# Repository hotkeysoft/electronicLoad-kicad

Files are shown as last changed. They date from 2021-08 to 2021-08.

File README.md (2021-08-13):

# Electronic Load
Rev A July 2021

***Work in progress, do not use***

- USB Powered (USB-B Connector)
- 0-24V DC Input
- Adjustable current range: 0-4A
- I2C OLED 0.96" Display
- Rotary Encoder w/switch
- Temperature Sensors w/hardware shutdown
- 5V Cooling fan (PWM Speed Control)

Images
============
|Front | Back |
|---|---|
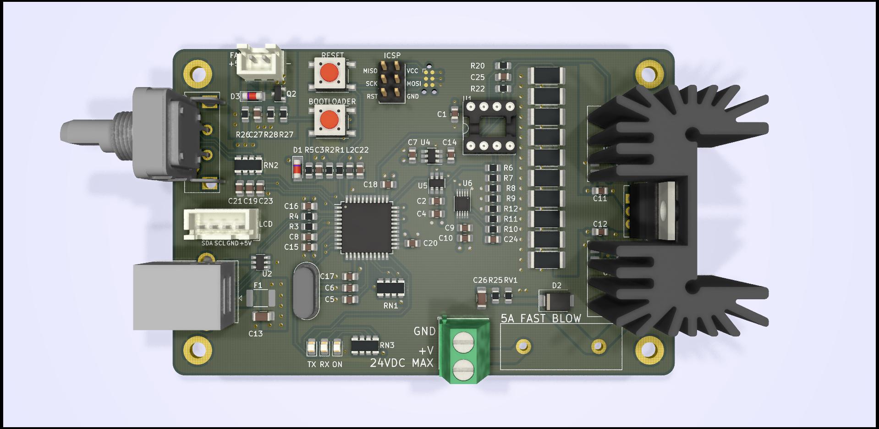
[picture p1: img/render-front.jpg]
Render Front
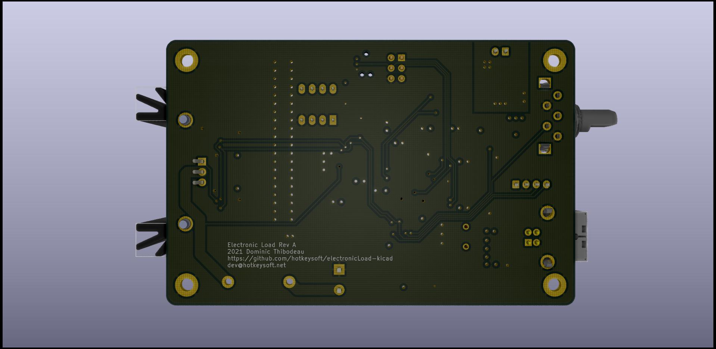
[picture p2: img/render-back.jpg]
Render Back
|||

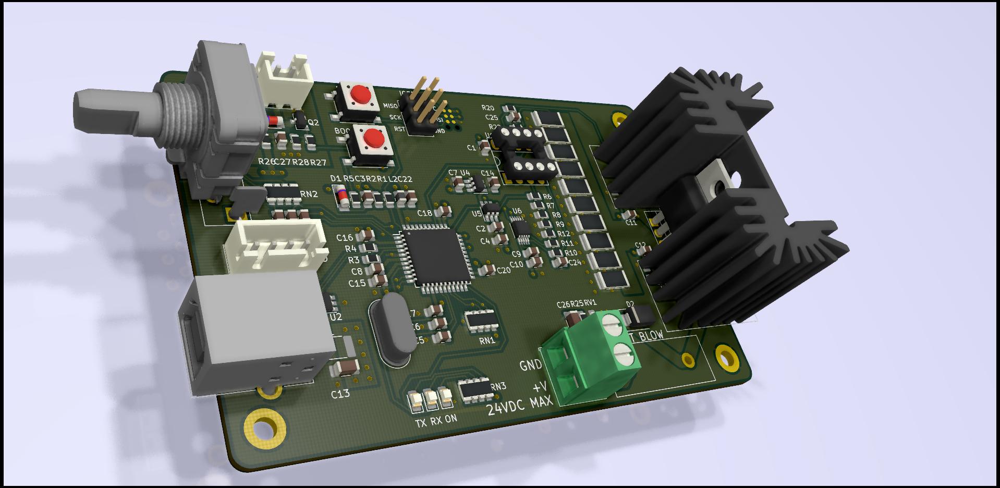
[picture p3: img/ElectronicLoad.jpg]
Render


### Schematics (pdf)
- [Complete schematics](./img/schema.pdf)

### PCB Images (svg)
- [Top](./img/pcb-front.svg)
- [GND Plane](./img/pcb-in1.svg)
- [VCC Plane](./img/pcb-in2.svg)
- [Bottom](./img/pcb-back.svg)

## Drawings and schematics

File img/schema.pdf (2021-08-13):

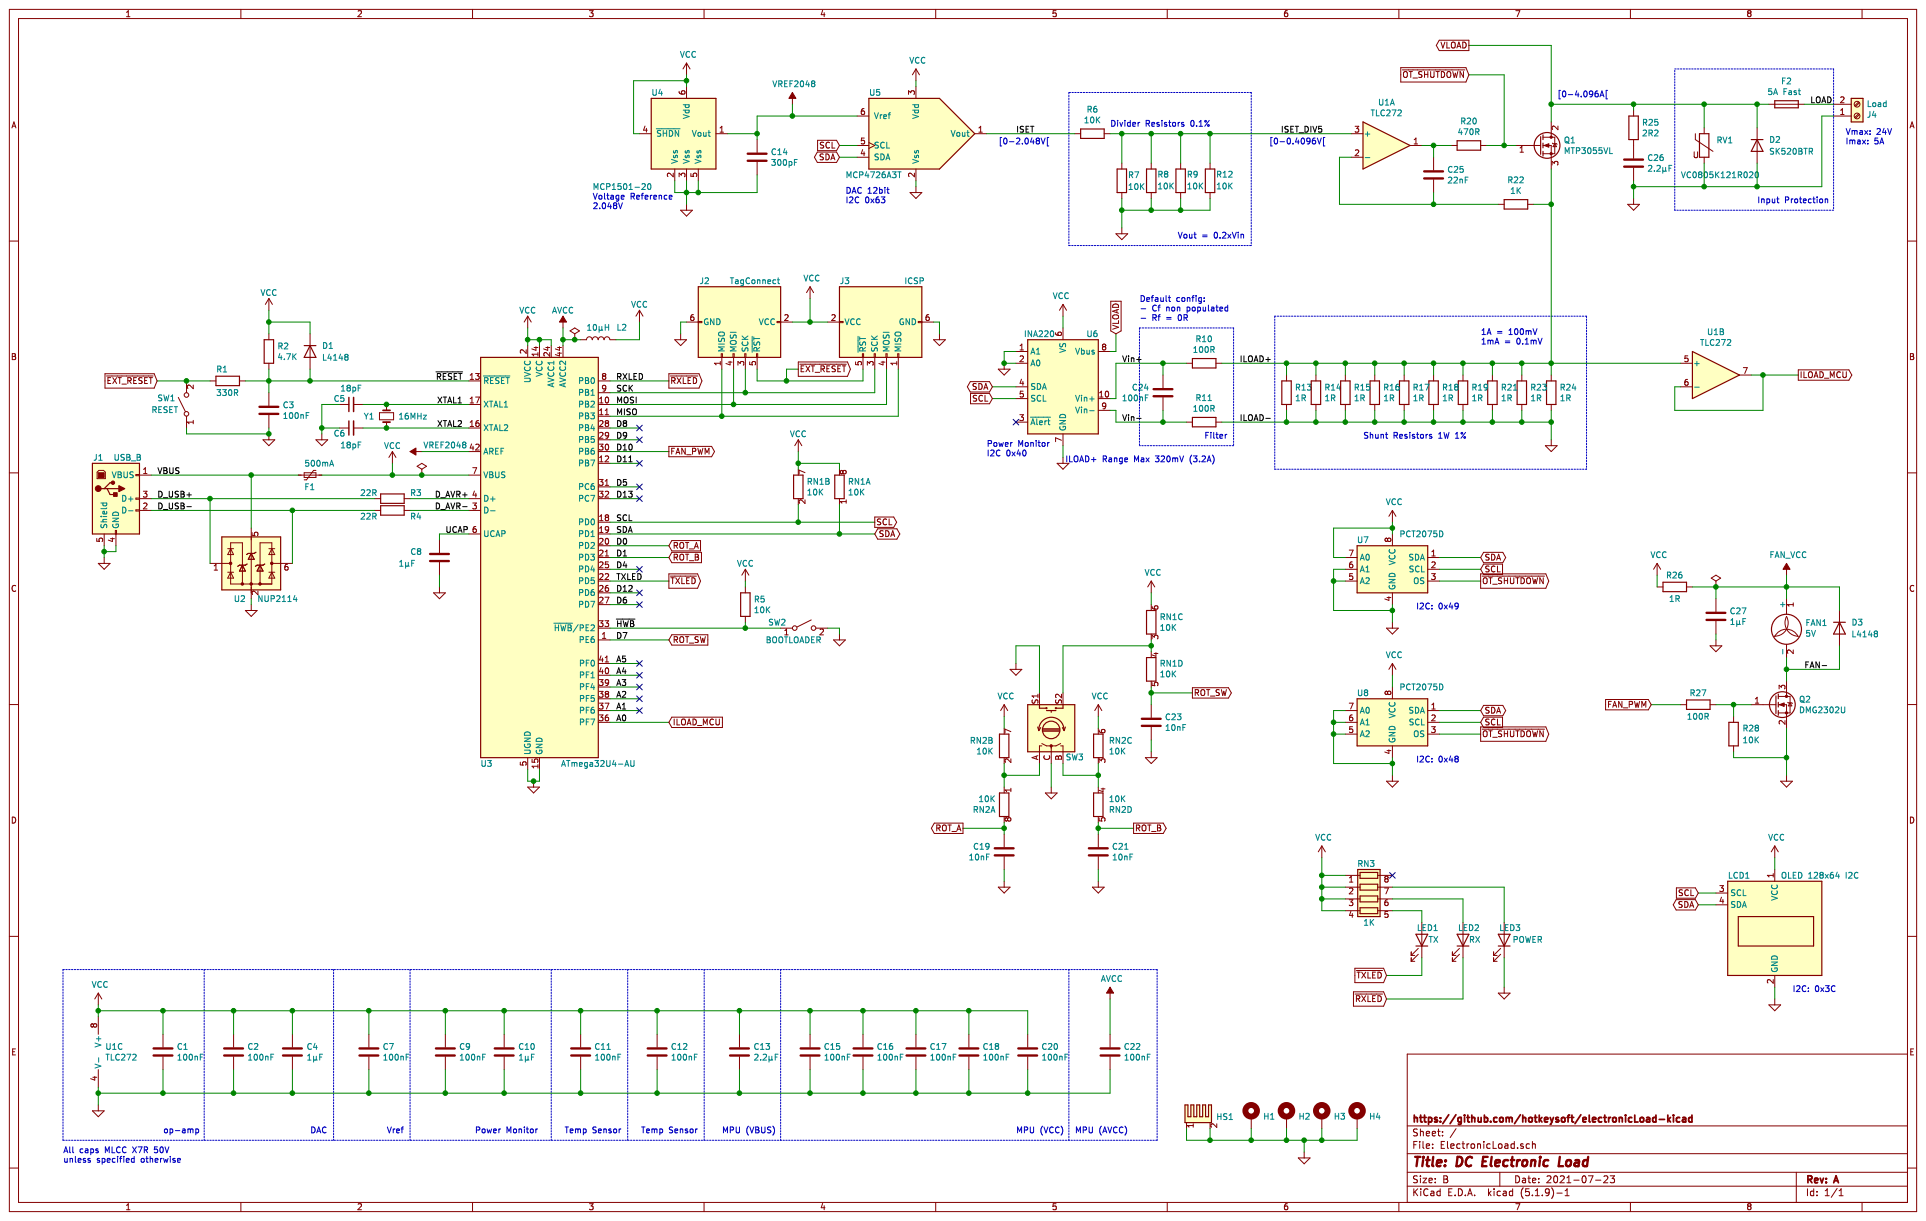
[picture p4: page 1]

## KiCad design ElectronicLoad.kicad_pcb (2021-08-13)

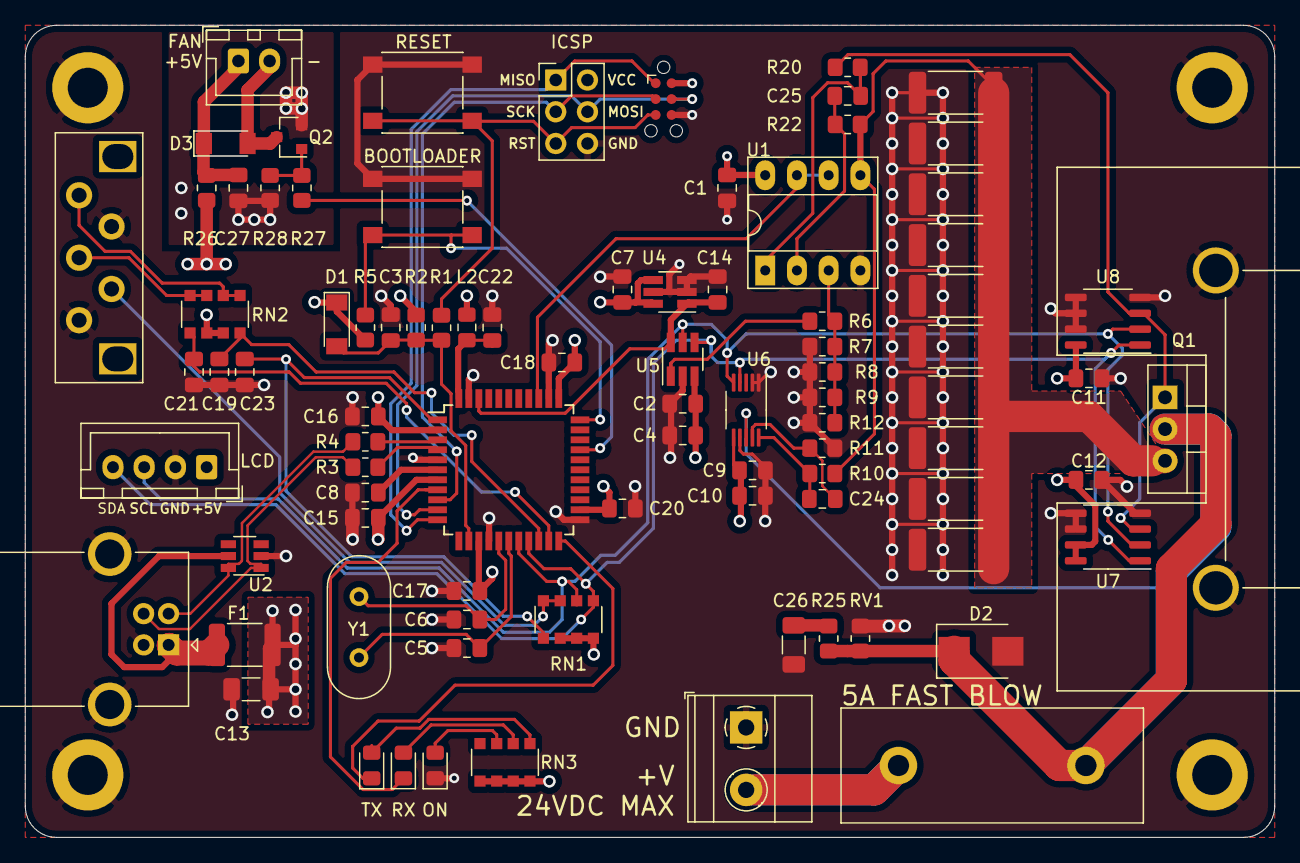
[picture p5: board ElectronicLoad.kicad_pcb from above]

Board: 4 copper layers, 100.0 x 65.0 mm, 93 parts (0 on the bottom side), 47 nets.

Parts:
C1, C2, C3, C7, C9, C11, C12, C15, C16, C17, C18, C20, C22, C24: 100nF; C_0805_2012Metric_Pad1.18x1.45mm_HandSolder
C4, C8, C10, C27: 1μF; C_0805_2012Metric_Pad1.18x1.45mm_HandSolder
C5, C6: 18pF; C_0805_2012Metric_Pad1.18x1.45mm_HandSolder
C13, C26: 2.2μF; C_1206_3216Metric_Pad1.33x1.80mm_HandSolder
C14: 300pF; C_0805_2012Metric_Pad1.18x1.45mm_HandSolder
C19, C21, C23: 10nF; C_0805_2012Metric_Pad1.18x1.45mm_HandSolder
C25: 22nF; C_0805_2012Metric_Pad1.18x1.45mm_HandSolder
D1, D3: L4148; D_MiniMELF
D2: SK520BTR; D_SMB
F1: 500mA; Fuse_1812_4532Metric_Pad1.30x3.40mm_HandSolder
F2: 5A Fast; Fuse_PTF-76
FAN1: 5V; JST_XH_B2B-XH-A_1x02_P2.50mm_Vertical
H1, H2, H3, H4: MountingHole_Pad; MountingHole_3.2mm_M3_ISO7380_Pad
HS1: Heatsink; HSINK_6396BG
J1: USB_B; USB_B_OST_USB-B1HSxx_Horizontal
J2: TagConnect; Tag-Connect_TC2030-IDC-NL_2x03_P1.27mm_Vertical
J3: ICSP; PinHeader_2x03_P2.54mm_Vertical
J4: Load; TerminalBlock_Phoenix_MKDS-1,5-2_1x02_P5.00mm_Horizontal
L2: 10μH; L_0805_2012Metric_Pad1.15x1.40mm_HandSolder
LCD1: OLED 128x64 I2C; JST_XH_B4B-XH-A_1x04_P2.50mm_Vertical
LED1: TX; LED_0805_2012Metric_Pad1.15x1.40mm_HandSolder
LED2: RX; LED_0805_2012Metric_Pad1.15x1.40mm_HandSolder
LED3: POWER; LED_0805_2012Metric_Pad1.15x1.40mm_HandSolder
Q1: MTP3055VL; TO-220-3_Vertical
Q2: DMG2302U; SOT-23
R1: 330R; R_0805_2012Metric_Pad1.20x1.40mm_HandSolder
R2: 4.7K; R_0805_2012Metric_Pad1.20x1.40mm_HandSolder
R3, R4: 22R; R_0805_2012Metric_Pad1.20x1.40mm_HandSolder
R5, R6, R7, R8, R9, R12, R28: 10K; R_0805_2012Metric_Pad1.20x1.40mm_HandSolder
R10, R11, R27: 100R; R_0805_2012Metric_Pad1.20x1.40mm_HandSolder
R13, R14, R15, R16, R17, R18, R19, R21, R23, R24: 1R; R_2512_6332Metric_Pad1.40x3.35mm_HandSolder
R20: 470R; R_0805_2012Metric_Pad1.20x1.40mm_HandSolder
R22: 1K; R_0805_2012Metric_Pad1.20x1.40mm_HandSolder
R25: 2R2; R_0805_2012Metric_Pad1.20x1.40mm_HandSolder
R26: 1R; R_0805_2012Metric_Pad1.20x1.40mm_HandSolder
RN1, RN2: 10K; R_Array_Convex_4x1206
RN3: 1K; R_Array_Convex_4x1206
RV1: VC0805K121R020; R_0805_2012Metric_Pad1.20x1.40mm_HandSolder
SW1: RESET; SW_SPST_PTS645
SW2: BOOTLOADER; SW_SPST_PTS645
SW3: Control; RotaryEncoder_Bourns_PEC16-2xxxF-Sxxxx
U1: TLC272; DIP-8_W7.62mm_Socket_LongPads
U2: NUP2114; TSOT-23-6
U3: ATmega32U4-AU; TQFP-44_10x10mm_P0.8mm
U4: MCP1501-20; SOT-23-6_Handsoldering
U5: MCP4726A3T; SOT-23-6_Handsoldering
U6: INA220; VSSOP-10_3x3mm_P0.5mm
U7, U8: PCT2075D; SO-8_3.9x4.9mm_P1.27mm
Y1: 16MHz; Crystal_HC49-4H_Vertical

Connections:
/D_AVR+: R3.2, U3.4
/D_AVR-: R4.2, U3.3
/D_USB+: J1.3, R3.1, U2.1
/D_USB-: J1.2, R4.1, U2.6
/FAN-: D3.2, FAN1.2, Q2.3
/ILOAD+: Q1.3, R10.2, R13.1, R14.1, R15.1, R16.1, R17.1, R18.1, R19.1, R21.1, R22.1, R23.1, R24.1, U1.5
/ISET: R6.2, U5.1
/ISET_DIV5: R6.1, R7.1, R8.2, R9.2, R12.2, U1.3
/LOAD: F2.1, J4.2
/MISO: J2.1, J3.1, U3.11
/MOSI: J2.4, J3.4, U3.10
/SCK: J2.3, J3.3, U3.9
/UCAP: C8.1, U3.6
/VBUS: F1.2, J1.1, U2.5
/Vin+: C24.1, R10.1, U6.10
/Vin-: C24.2, R11.1, U6.9
/XTAL1: C5.2, U3.17, Y1.1
/XTAL2: C6.2, U3.16, Y1.2
/~HWB: R5.2, SW2.1, U3.33
/~RESET: C3.1, D1.2, R1.1, R2.2, U3.13
AVCC: C22.1, L2.2, U3.44
FAN_PWM: R27.1, U3.30
FAN_VCC: C27.1, D3.1, FAN1.1, R26.2
GND: C1.2, C2.2, C3.2, C4.2, C5.1, C6.1, C7.2, C8.2, C9.2, C10.2, C11.2, C12.2, C13.2, C14.2, C15.2, C16.2, C17.2, C18.2, C19.2, C20.2, C21.2, C22.2, C23.2, C26.2, C27.2, D2.2, H1.1, H2.1, H3.1, H4.1, HS1.1, HS1.2, J1.4, J1.5, J2.6, J3.6, J4.1, LCD1.2, LED3.1, Q2.2, R7.2, R8.1, R9.1, R11.2, R12.1, R13.2, R14.2, R15.2, R16.2, R17.2, R18.2, R19.2, R21.2, R23.2, R24.2, R28.2, RV1.2, SW1.1, SW2.2, SW3.C, SW3.S1, U1.4, U2.2, U3.5, U3.15, U3.23, U3.35, U3.43, U4.2, U4.3, U4.5, U5.2, U6.1, U6.2, U6.7, U7.4, U7.5, U7.6, U8.4, U8.5, U8.6, U8.7
ILOAD_MCU: U1.6, U1.7, U3.36
unnamed: C25.1, R20.2, U1.1
unnamed: C25.2, R22.2, U1.2
unnamed: C26.1, R25.2
unnamed: LED1.2, RN3.5
unnamed: LED2.2, RN3.6
unnamed: LED3.2, RN3.7
unnamed: Q2.1, R27.2, R28.1
unnamed: RN1.3, RN1.4, SW3.S2
unnamed: RN2.1, RN2.2, SW3.A
unnamed: RN2.3, RN2.4, SW3.B
ROT_A: C19.1, RN2.8, U3.20
ROT_B: C21.1, RN2.5, U3.21
ROT_SW: C23.1, RN1.5, U3.1
SCL: LCD1.3, RN1.2, U3.18, U5.5, U6.5, U7.2, U8.2
SDA: LCD1.4, RN1.1, U3.19, U5.4, U6.4, U7.1, U8.1
VCC: C1.1, C2.1, C4.1, C7.1, C9.1, C10.1, C11.1, C12.1, C13.1, C15.1, C16.1, C17.1, C18.1, C20.1, D1.1, F1.1, J2.2, J3.2, L2.1, LCD1.1, R2.1, R5.1, R26.1, RN1.6, RN1.7, RN1.8, RN2.6, RN2.7, RN3.1, RN3.2, RN3.3, RN3.4, U1.8, U3.2, U3.7, U3.14, U3.24, U3.34, U4.4, U4.6, U5.3, U6.6, U7.7, U7.8, U8.8
VLOAD: D2.1, F2.2, Q1.2, R25.1, RV1.1, U6.8
VREF2048: C14.1, U3.42, U4.1, U5.6
~EXT_RESET: J2.5, J3.5, R1.2, SW1.2
~OT_SHUTDOWN: Q1.1, R20.1, U7.3, U8.3
~RXLED: LED2.1, U3.8
~TXLED: LED1.1, U3.22

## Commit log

2021-07-24 Initial import
    [ElectronicLoad.kicad_pcb, ElectronicLoad.sch]
2021-07-25 USB, MCU
    [ElectronicLoad.kicad_pcb, ElectronicLoad.sch]
2021-07-25 Fan control
    [ElectronicLoad.kicad_pcb, ElectronicLoad.sch]
2021-07-26 Power switch, led
    [ElectronicLoad.kicad_pcb, ElectronicLoad.sch]
2021-07-31 Encoder, layout
    [ElectronicLoad.kicad_pcb, ElectronicLoad.sch]
2021-08-05 Heatsink, Fan, Layout
    [ElectronicLoad.kicad_pcb, ElectronicLoad.sch]
2021-08-08 Move input connector, routing, silkscreen
    [ElectronicLoad.kicad_pcb, ElectronicLoad.sch]
2021-08-08 Move FAN_PWM to D10
    [ElectronicLoad.kicad_pcb, ElectronicLoad.sch]
2021-08-09 Reduced decoupling capacitance on VBUS to <10uF
    [ElectronicLoad.kicad_pcb, ElectronicLoad.sch]
2021-08-10 3d model for rotary encoder
    [ElectronicLoad.kicad_pcb]
2021-08-11 Relabel components
    [ElectronicLoad.kicad_pcb, ElectronicLoad.sch]
2021-08-13 Move connectors
    [ElectronicLoad.kicad_pcb]
2021-08-13 Add plot
    [ElectronicLoad-B_Cu.gbl, ElectronicLoad-B_Mask.gbs, ElectronicLoad-B_SilkS.gbo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]
2021-08-13 Tweak rotary switch footprint
    [ElectronicLoad-B_Cu.gbl, ElectronicLoad-B_Mask.gbs, ElectronicLoad-B_SilkS.gbo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]
